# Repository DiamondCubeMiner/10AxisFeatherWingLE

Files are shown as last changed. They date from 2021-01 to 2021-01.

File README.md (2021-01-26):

# 10AxisFeatherWingLE #
A 10-DOF Featherwing, powered by LSM9DS1 and BMP280.

## Description ##
This featherwing uses I2C to connect both the IMU (LSM9DS1) and the altimeter (BMP280) to the Feather.
I made this to design projects that require a 10-DOF IMU in a tiny package where breakouts can affect the weight a lot and may not be a good option, such as a quadcopter, a model plane, or a model rocket.

## Drivers ##
These drivers should work as the project is a derivative of SparkFun hardware:
  - [SparkFun_LSM9DS1_Arduino_Library](https://github.com/sparkfun/SparkFun_LSM9DS1_Arduino_Library)
  - [SparkFun_BME280_Arduino_Library](https://github.com/sparkfun/SparkFun_BME280_Arduino_Library)

## Thanks ##
This project is derived from the following projects:
  - [SparkFun 9DoF Sensor Stick](https://github.com/sparkfun/9DOF_Sensor_Stick)
  - [SparkFun Atmospheric Sensor Breakout - BME280 (Qwiic)](https://github.com/sparkfun/Qwiic_Atmospheric_Sensor_Breakout_BME280)

Thanks to Sparkfun for their open-source schematics and libraries!

## License ##
This work is licensed under the Creative Commons Attribution-ShareAlike 4.0 International License. To view a copy of this license, visit http://creativecommons.org/licenses/by-sa/4.0/ or send a letter to Creative Commons, PO Box 1866, Mountain View, CA 94042, USA.

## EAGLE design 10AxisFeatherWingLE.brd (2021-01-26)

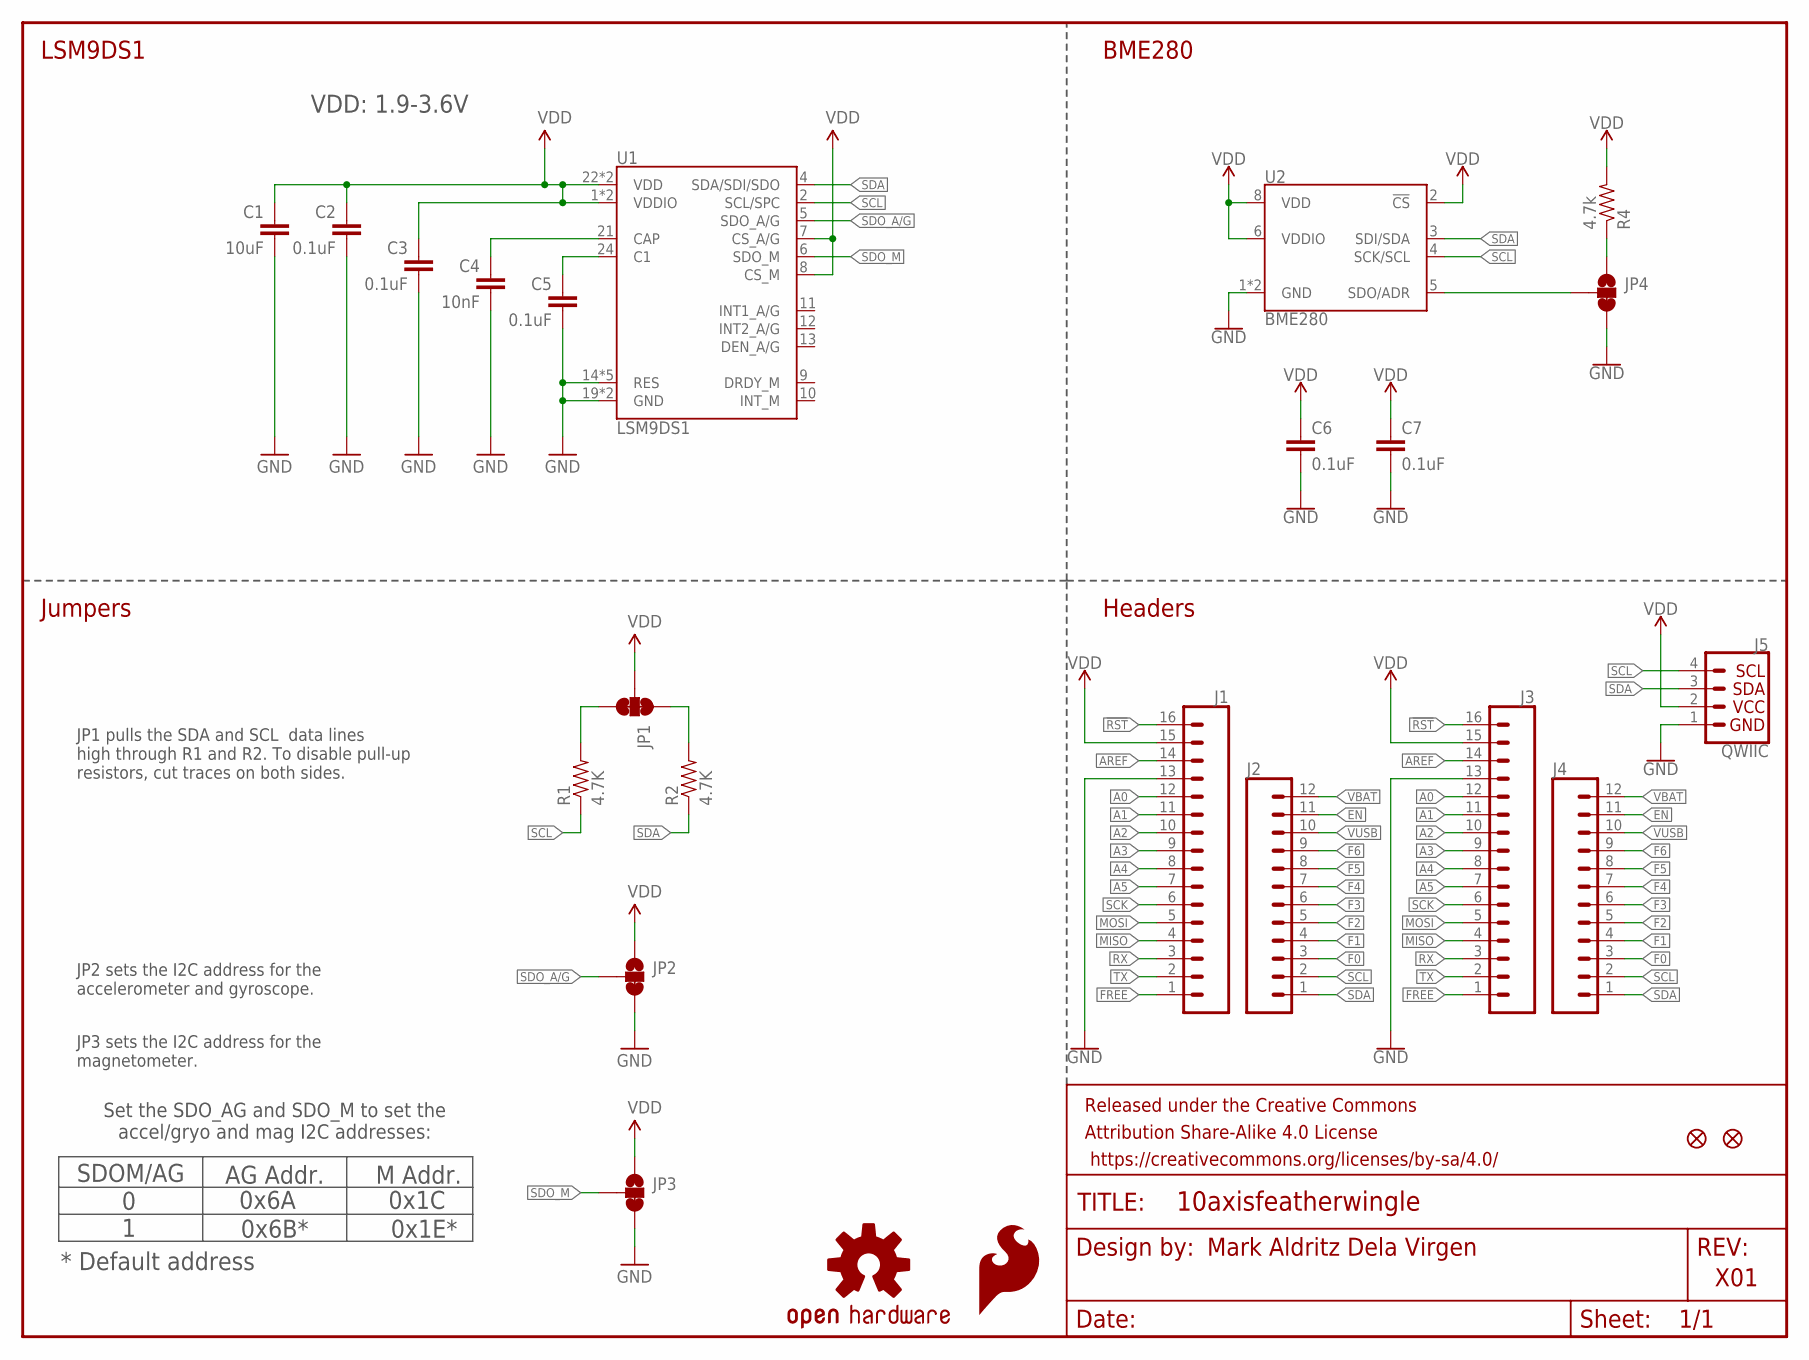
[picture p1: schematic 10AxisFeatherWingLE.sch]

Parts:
C1: 10uF; 0603-CAP@1
C2, C3, C5: 0.1uF; 0603-CAP@1
C4: 10nF; 0603-CAP@1
C6, C7: 0.1uF; 0603
FD3, FD4: FIDUCIALUFIDUCIAL; MICRO-FIDUCIAL
FRAME1: FRAME-LETTER; CREATIVE_COMMONS
J1, J3: CONN_161X16_NO_SILK; 1X16_NO_SILK
J2, J4: CONN_12NO_SILK; 1X12_NO_SILK
J5: QWIIC; 1X04_1MM_RA
JP1: JUMPER-SMT_3_2-NC_TRACE_SILK; SMT-JUMPER_3_2-NC_TRACE_SILK
JP2, JP3, JP4: JUMPER-SMT_3_1-NC_TRACE_SILK; SMT-JUMPER_3_1-NC_TRACE_SILK
LOGO1: SFE_LOGO_FLAME.1_INCH; SFE_LOGO_FLAME_.1
LOGO3: OSHW-LOGOMINI; OSHW-LOGO-MINI
R1, R2: 4.7K; 0603-RES
R4: 4.7k; 0603
U1: LSM9DS1; LGA24-8X4
U2: BME280; LGA-8-2.5X2.5

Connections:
!RST: J1.16, J3.16
A0: J1.12, J3.12
A1: J1.11, J3.11
A2: J1.10, J3.10
A3: J1.9, J3.9
A4: J1.8, J3.8
A5: J1.7, J3.7
AREF: J1.14, J3.14
EN: J2.11, J4.11
F0: J2.3, J4.3
F1: J2.4, J4.4
F2: J2.5, J4.5
F3: J2.6, J4.6
F4: J2.7, J4.7
F5: J2.8, J4.8
F6: J2.9, J4.9
FREE: J1.1, J3.1
GND: C1.2, C2.2, C3.2, C4.2, C5.2, C6.2, C7.2, J1.13, J3.13, J5.1, JP2.3, JP3.3, JP4.3, U1.14 (RES), U1.15 (RES), U1.16 (RES), U1.17 (RES), U1.18 (RES), U1.19 (GND), U1.20 (GND), U2.1 (GND), U2.7 (GND)
MISO: J1.4, J3.4
MOSI: J1.5, J3.5
unnamed: JP1.1, R2.2
unnamed: JP1.3, R1.2
unnamed: JP4.1, R4.1
unnamed: C4.1, U1.21 (CAP)
unnamed: C5.1, U1.24 (C1)
RX: J1.3, J3.3
SCK: J1.6, J3.6
SCL: J2.2, J4.2, J5.4, R1.1, U1.2 (SCL/SPC), U2.4 (SCK/SCL)
SDA: J2.1, J4.1, J5.3, R2.1, U1.4 (SDA/SDI/SDO), U2.3 (SDI/SDA)
SDO: JP4.2, U2.5 (SDO/ADR)
SDO_A/G: JP2.2, U1.5 (SDO_A/G)
SDO_M: JP3.2, U1.6 (SDO_M)
TX: J1.2, J3.2
VBAT: J2.12, J4.12
VDD: C1.1, C2.1, C3.1, C6.1, C7.1, J1.15, J3.15, J5.2, JP1.2, JP2.1, JP3.1, R4.2, U1.1 (VDDIO), U1.3 (VDDIO), U1.7 (CS_A/G), U1.8 (CS_M), U1.22 (VDD), U1.23 (VDD), U2.2 (!CS), U2.6 (VDDIO), U2.8 (VDD)
VUSB: J2.10, J4.10

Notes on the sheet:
Mark Aldritz Dela Virgen
X01
LSM9DS1
SDOM/AG
AG Addr.
0 1
M Addr.
Set the SDO_AG and SDO_M to set the accel/gryo and mag I2C addresses:
BME280
Headers
Jumpers
JP1 pulls the SDA and SCL data lines high through R1 and R2. To disable pull-up resistors, cut traces on both sides.
JP2 sets the I2C address for the accelerometer and gyroscope.
JP3 sets the I2C address for the magnetometer.
0x6A
0x6B*
0x1C
0x1E*
* Default address
VDD: 1.9-3.6V

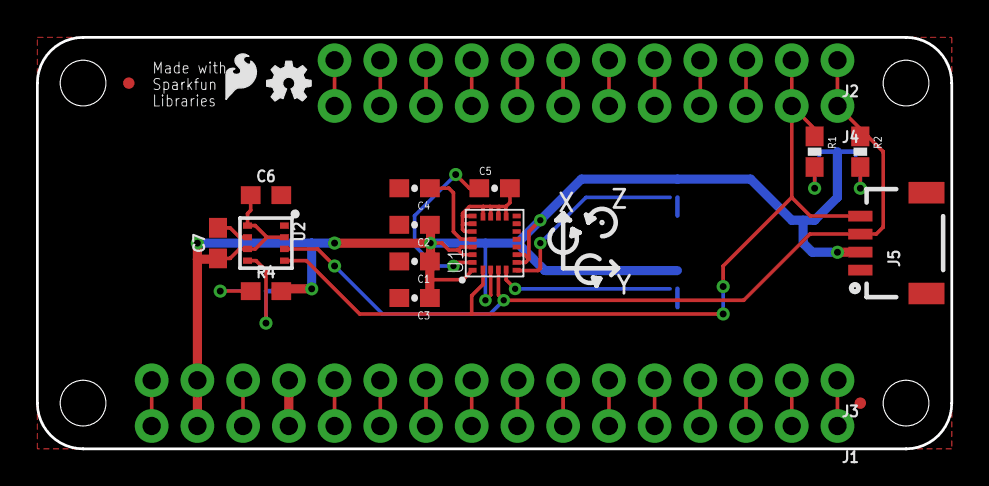
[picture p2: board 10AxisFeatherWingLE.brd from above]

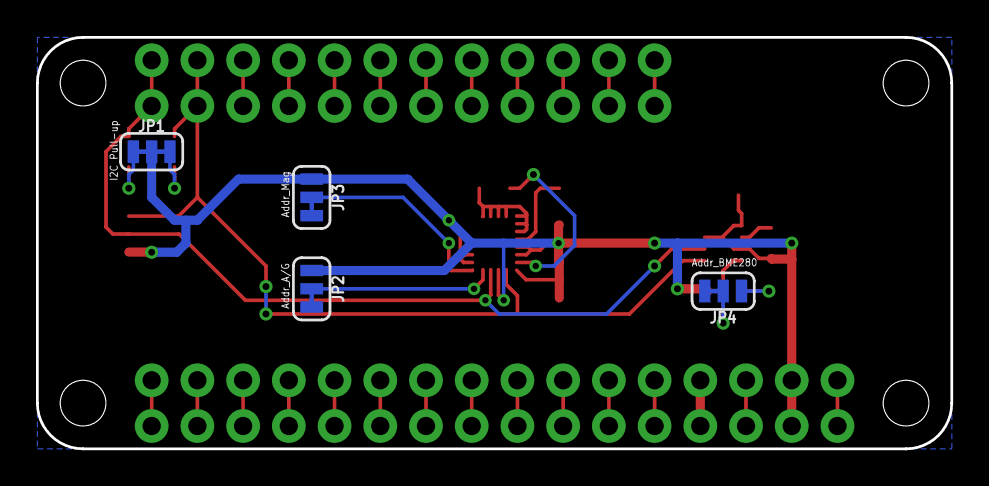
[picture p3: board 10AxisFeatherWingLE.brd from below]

Board: 2 copper layers, 50.8 x 22.9 mm, 26 parts (4 on the bottom side), 36 nets.

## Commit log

2019-12-22 Initial upload
    [10AxisFeatherWingLE.brd, 10AxisFeatherWingLE.sch]
2019-12-24 Added new features
    Added breakouts and silk text.
    [10AxisFeatherWingLE.brd, 10AxisFeatherWingLE.sch]
2019-12-26 Board silk edit
    [10AxisFeatherWingLE.brd]
2019-12-31 Migration to KiCad
    [10AxisFeatherWingLE.kicad_pcb, 10AxisFeatherWingLE.sch]
2020-01-05 Corrected capacitor values
    CAP and C1 capacitors were flipped, fixed
    [10AxisFeatherWingLE.kicad_pcb, 10AxisFeatherWingLE.sch]
2020-01-07 Minor format fix
    [10AxisFeatherWingLE.kicad_pcb, 10AxisFeatherWingLE.sch]
2020-01-12 Increased trace width
    [10AxisFeatherWingLE.kicad_pcb, 10AxisFeatherWingLE.sch]
2020-01-17 Changed grove connector to STEMMA
    [10AxisFeatherWingLE.kicad_pcb, 10AxisFeatherWingLE.sch]
2020-02-06 Removed STEMMA connector
    STEMMA requires the use of a 3.3V to 5V level shifter and voltage regulator.
    The board does not support these features, so they were removed.
    [10AxisFeatherWingLE.kicad_pcb, 10AxisFeatherWingLE.sch]
2020-11-18 Eagle Refactor
    Remade the project in EAGLE. Needs signal routing.
    [10AxisFeatherWingLE.brd, 10AxisFeatherWingLE.kicad_pcb, 10AxisFeatherWingLE.sch]
2021-01-26 Added traces
    Added traces to board file.
    [10AxisFeatherWingLE.brd, 10AxisFeatherWingLE.sch]

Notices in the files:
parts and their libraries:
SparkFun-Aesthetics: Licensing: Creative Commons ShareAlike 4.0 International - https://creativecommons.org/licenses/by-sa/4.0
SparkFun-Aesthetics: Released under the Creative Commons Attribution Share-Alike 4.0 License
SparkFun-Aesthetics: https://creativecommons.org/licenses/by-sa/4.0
